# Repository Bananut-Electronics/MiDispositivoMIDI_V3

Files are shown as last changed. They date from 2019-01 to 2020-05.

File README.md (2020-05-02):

<h1 align="center"> ⭐️ MiDispositivoMIDI V3 ⭐️ </h1>

*This repository is no longer officially maintained but feel free to open a pull request with your contribution. As we ran out of devices, we don't sell it anymore, but if you you want one you can find here all the schematics, manuals, documentations and code to build your own.*
<!-- ALL-CONTRIBUTORS-BADGE:START - Do not remove or modify this section -->

<!-- ALL-CONTRIBUTORS-BADGE:END -->


<p align="center">
  <a href="www.facebook.com/bananutelectronics">
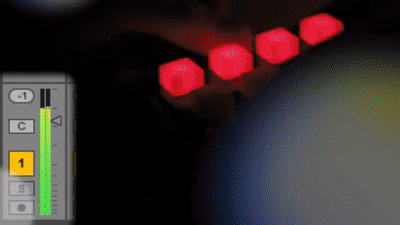
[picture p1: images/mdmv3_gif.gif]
    
  </a>
  
<p align="center">
  Connect our device to your computer and start making music! Totally Plug&Play without any extra software, just your favourite MIDI sequencer (Logic, Ableto, Nuendo). It is not only a great tool for making music and experimenting, you can also use it to learn more about electronics, programming and Arduino. You have tons of code examples ready to load, but if you feel up to it, you can also contribute with your code. And last but not least! It is open source! You can either buy it at our website, our build it yourself, all the schematics and code are available in this repository.
  <p align="center">
  <a href="www.facebook.com/bananutelectronics">
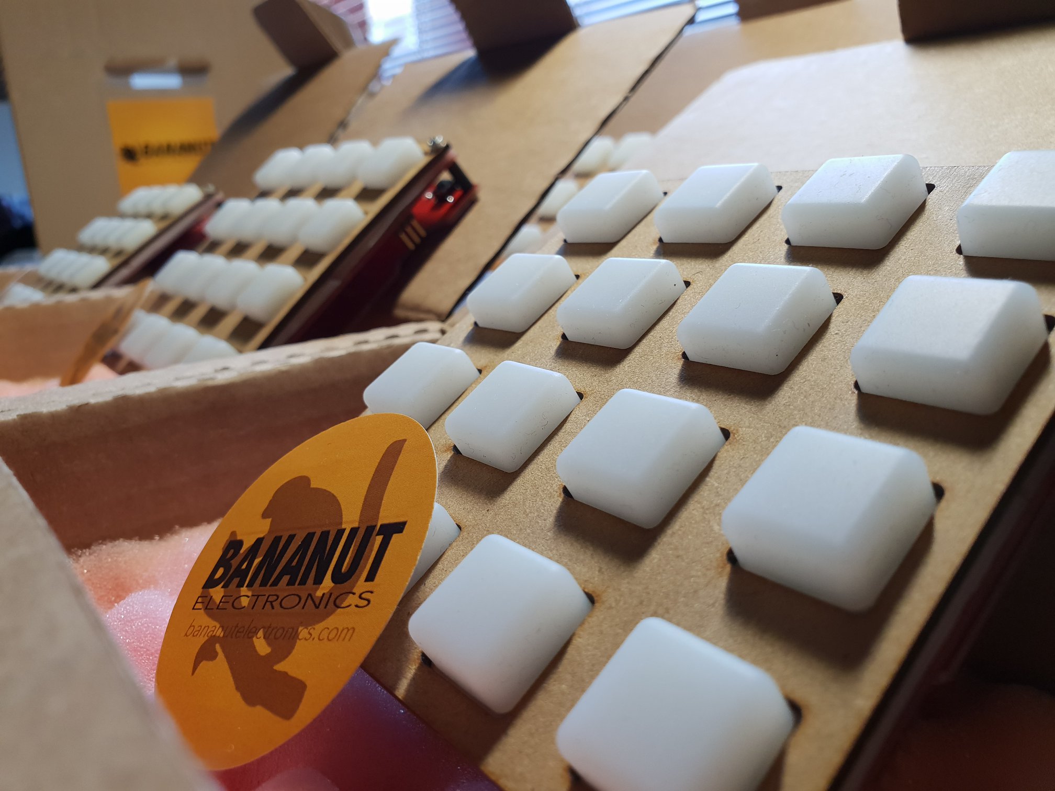
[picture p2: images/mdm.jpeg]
    
  </a>
</p>
</p>

---

<h2 align="center">❤️ Follow us! ❤️</h2>
<p align="center">
  <a href="https://www.facebook.com/bananutelectronics">
</a>
  
  <a href="https://www.instagram.com/bananutelectronics">
</a>

  <a href="https://github.com/Bananut-Electronics/">
</a>

  <a href="https://www.youtube.com/channel/UCHQbpOPa1lVauoBouRJ16Iw">
</a>

  <a href="https://twitter.com/bn_electronics">
</a>
</p>

---

<h2 align="center">💶 Want to buy the product? 💶</h2>

<p align="center">
  
</p>

---

<h2 align="center">📗 Index 📗</h2>

<p align="center">
  <a href="#about-us">About us</a> •
  <a href="#midispositivomidi-v3">MiDispositivoMIDI V3</a> •
  <a href="#documentation">Documentation</a> •
  <a href="#expansions">Expansions</a> •
  <a href="#faq">FAQ</a> •
  <a href="#contributing">Contributing</a> •
  <a href="#license">License</a>
</p>

---

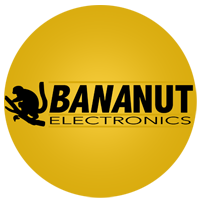
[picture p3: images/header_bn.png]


# About us
Hi! We are BanaNut Electronics and we develop software and hardware for Arduino with educational purposes. We were born at the UPM University in Madrid during 2013 and we haven't stopped ever since.

<center>

| LightWand Kosmonaut V2 |  MiDispositivoMIDI V3 |
|:---:|:---:|
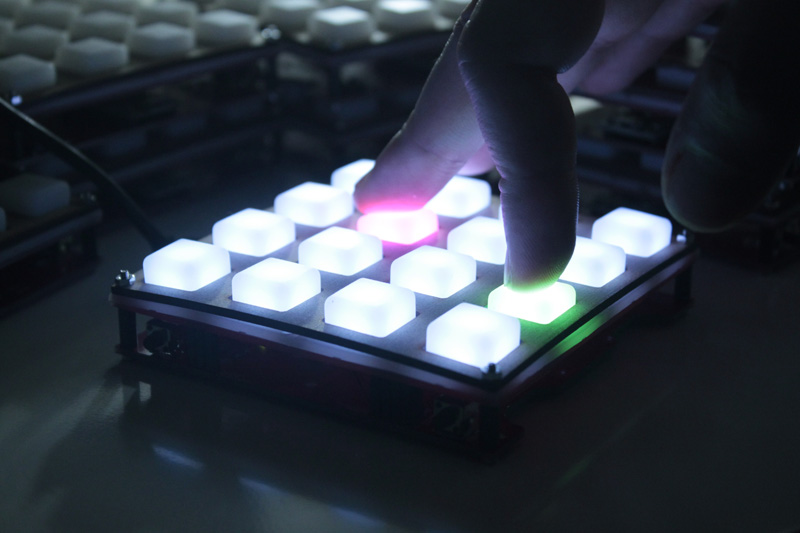
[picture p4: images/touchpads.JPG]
|   |  |

</center>

---

Everything started with the first version at the Polytechnical University of Madrid (UPM) in 2013. We were a couple of young students interested in music and electronics, and we came up with this idea. We started reusing some hardware, mainly found at SparkFun's website, but only one year later, we had the second version that was fully designed by us. After some trial and error and feedback from users and friends, we released this third version V3 in 2017. We not only released the code, but also we started producing devices and selling them on the internet, first in our web and later on at Tindie.com store.

During the years, the different versions of MiDispositivoMIDI have been used by many people, engineers, musicians and even kids. We gave some workshops at UPM Madrid for students in Electrical and Telecommunications Engineering, where we gave all the materials and the students had to solder, assembly and code the device.

<p align="center">
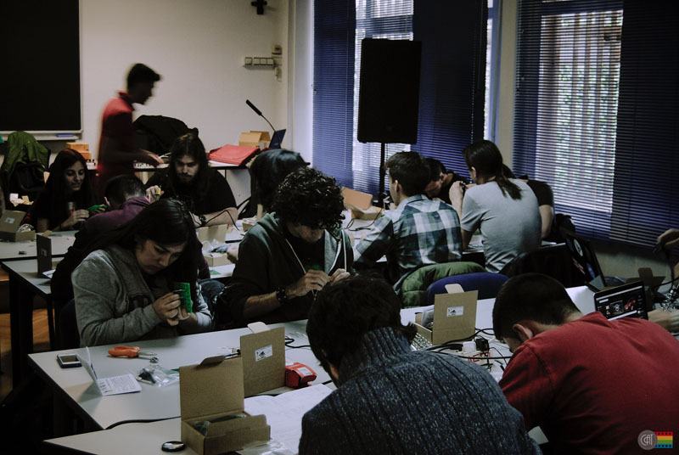
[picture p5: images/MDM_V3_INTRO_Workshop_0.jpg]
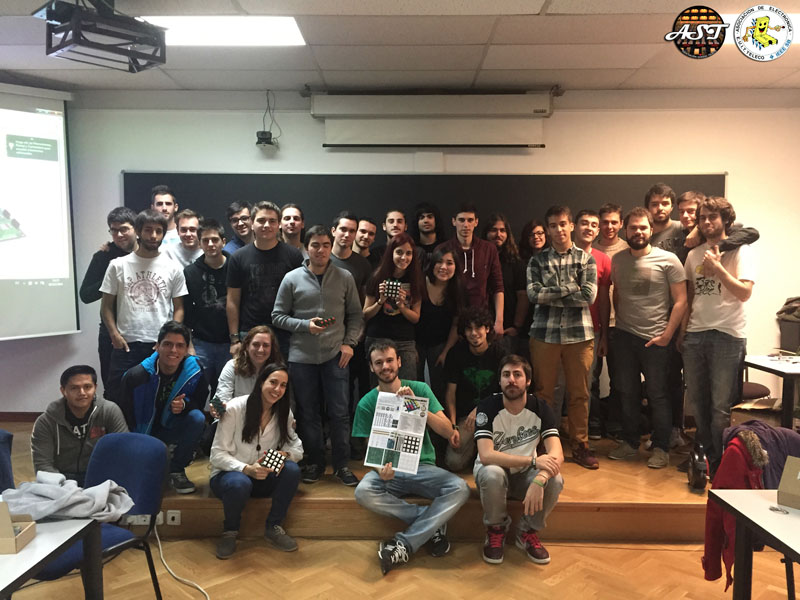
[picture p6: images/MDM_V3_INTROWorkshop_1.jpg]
  
</a>

---

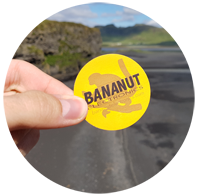
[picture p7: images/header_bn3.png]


# MiDispositivoMIDI V3
We are proud to present the MiDispositivoMIDI V3, which is the latest version we have out in the market (Jan 2019). MiDispositivoMIDI is an open source MIDI controller based on Arduino. In other words, its a small device with tons of LEDs and buttons, that you can connect to your computer to, in example, make music. Our device works with the MIDI protocol, a very well known protocol used in the music industry. You can just plug our device and start using it with your favourite DAW, such as Logic, Ableton or Cubase. No other extra softare is needed.

If you are also interested in programming and electronics, this device offer you a great tool to learn by example. You can also use it to prototype and play around. And also, since it is open source you can fully costumize it to your needs. If you don't know much about coding, just load the codes that we provide, and use them. But if you like coding, you can also publish your code with new features or improvements for others to use.

<p align="center">
<a href="www.facebook.com/bananutelectronics">
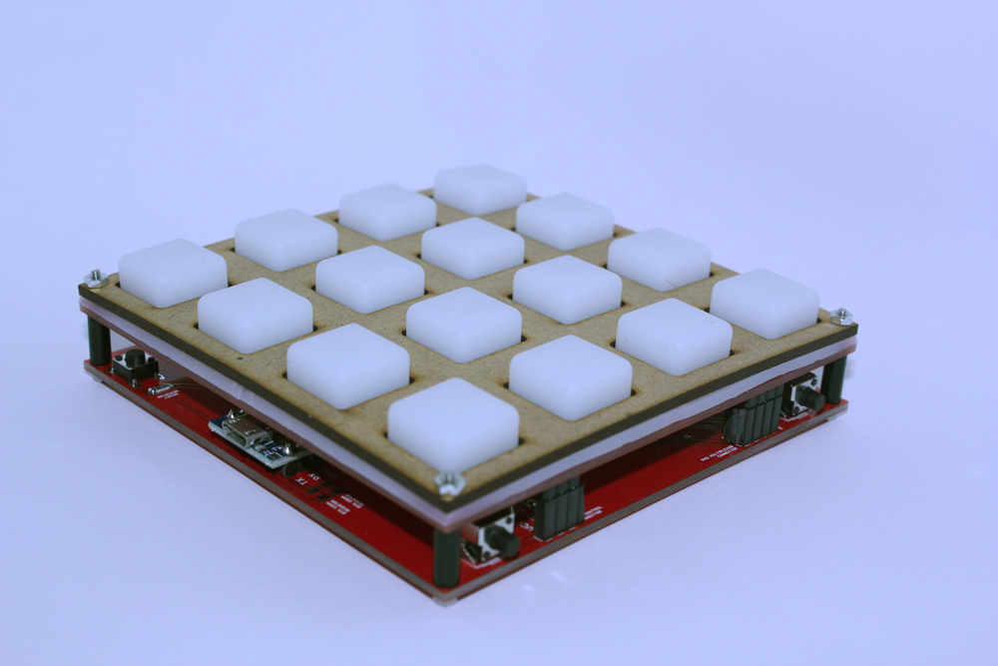
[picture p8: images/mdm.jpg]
    
</a>

<p align="center">
<a href="www.facebook.com/bananutelectronics">
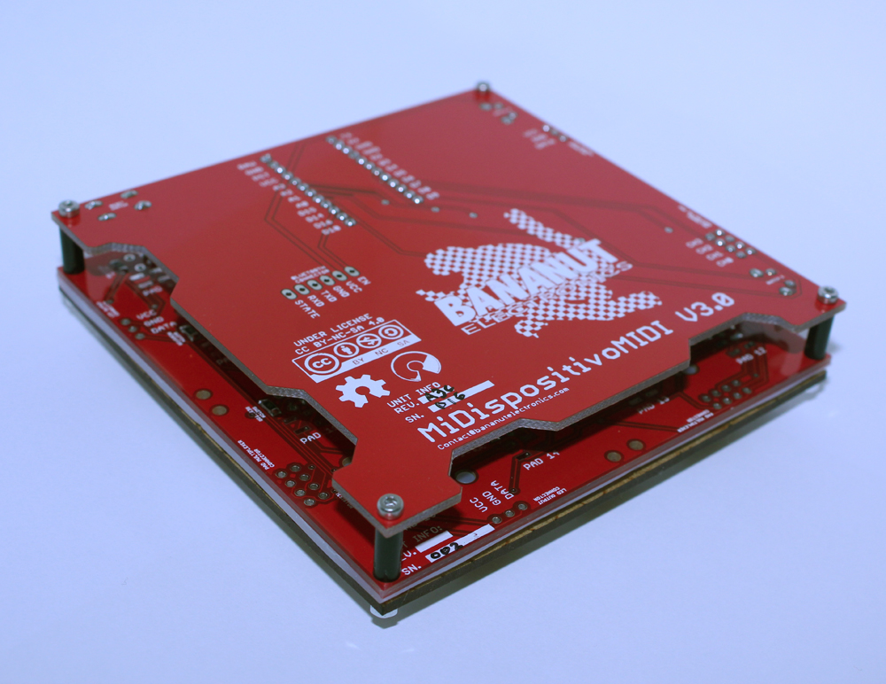
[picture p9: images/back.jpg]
    
</a>

These are the features of our device:
* Plug & Play MIDI device.
* Open source based on Arduino.
* Have 16 pad buttons in a 4x4 matrix.
* Have 2 lateral buttons.
* Have RGB leds with 256 levels of intensity of each color.
* Micro USB connection.
* Dimensions of 10x10 cm.
* Modular design. Connect up to 4 devices.
* Fully compatible with Logic, Ableton or Cubase.

<p align="center">
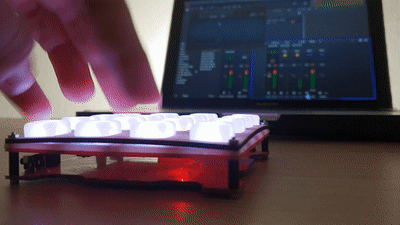
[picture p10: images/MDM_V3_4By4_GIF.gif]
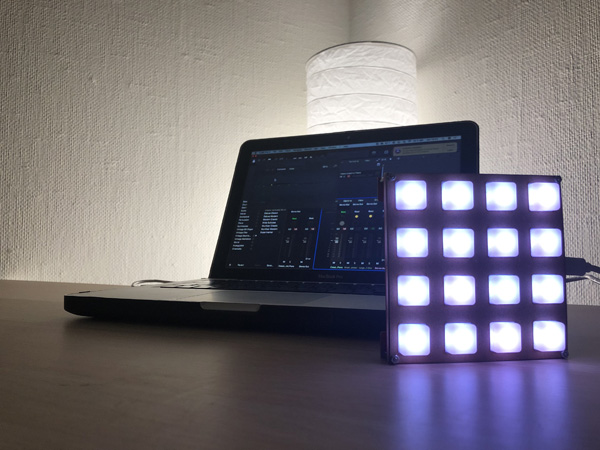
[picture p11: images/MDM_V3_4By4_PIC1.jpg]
  
</a>

We invite you to check our YouTube channel, where we post videos about our devices. You can also follow other social networks such as Instagram o Facebook.

* https://www.youtube.com/watch?v=3QnzLwpbpRE&t
* https://www.youtube.com/watch?v=8WFfShg-0Dk
* https://www.youtube.com/watch?v=2y8fhmTmedI
* https://www.youtube.com/watch?v=TsuVpFoLFyI

---

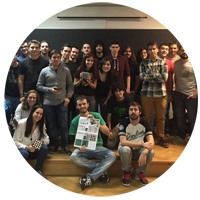
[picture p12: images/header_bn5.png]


# Documentation

We provide a C++ Arduino library that you can use with our device, that simplifies the tasks of handling the LEDs and buttons. The code is self documented, but we have also written a nice Wiki page where you can find more information about the hardware, some hints about MIDI protocol and some low level software examples in Arduino, that will allow you to understand how it works:
* Wiki: https://github.com/Bananut-Electronics/MiDispositivoMIDI_V3/wiki

TODO: Write some nice code snippets
```cpp
//TODO
```

---

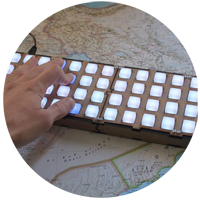
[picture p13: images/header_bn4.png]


# Expansions

Our device has a modular design, which means that with the same hardware, you can add modules to convert it into a bigger controller. For example, if you put four MiDispositivoMIDI V3 into a 8x8 configuration, you will have 64 buttons. All this can be done using the same hardware and with very few modificatons in the code. Note that you can also replace a 4x4 button matrix by a 4x4 potentiometer matrix, but this feature is not implemented yet.

<p align="center">
<a href="www.facebook.com/bananutelectronics">
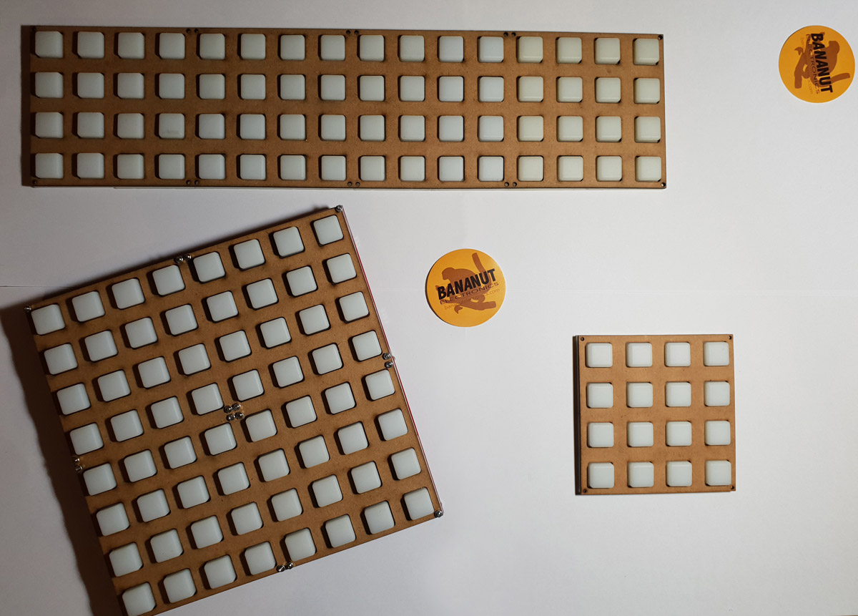
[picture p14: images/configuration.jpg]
    
</a>

## 4x16 Configuration

You can connect 4 MiDispositivoMIDI V3 in a 4x16 configuration to get the following. With something like this, you can, for example, create an step sequencer. See this video for an example:
* https://www.youtube.com/watch?v=bYyvVDn-gKs

<p align="center">
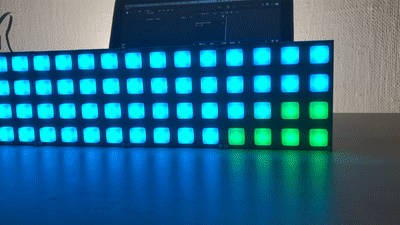
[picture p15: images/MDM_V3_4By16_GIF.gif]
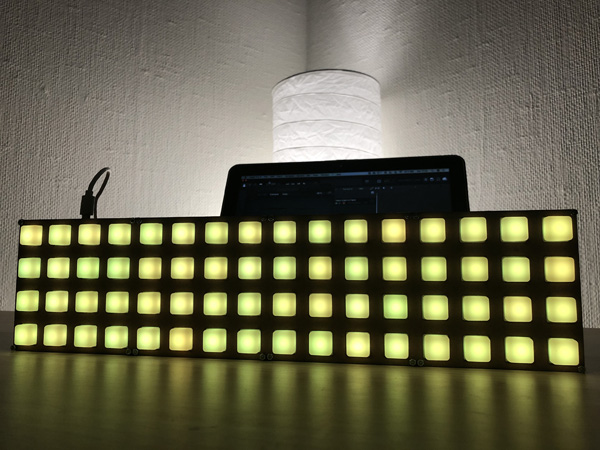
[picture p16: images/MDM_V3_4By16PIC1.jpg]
  
</a>

## 8x8 Configuration
Same as before, you can connect the devices with a different configuration. Note that the connections are done under the PCB with an extra PCB, so no extra wiring is needed.

<p align="center">
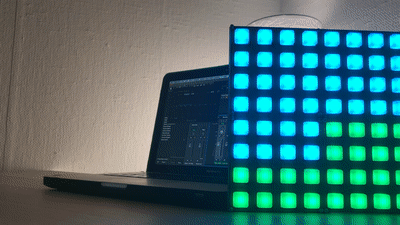
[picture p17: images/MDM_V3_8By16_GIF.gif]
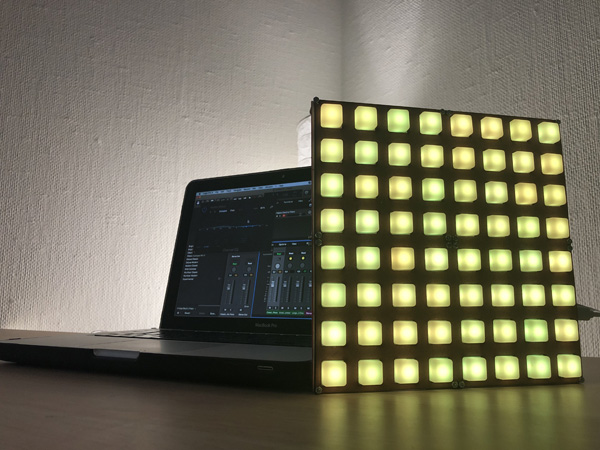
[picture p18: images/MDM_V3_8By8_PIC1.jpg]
  
</a>

## 4x8 Configuration
TODO

## Potentiometer Expansion
TODO

---

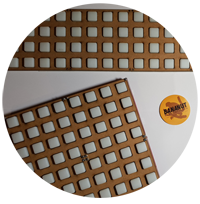
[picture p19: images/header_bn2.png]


# FAQ

Feel free to send us a mail to bananutelectronics@gmail.com if you have any question, but read before our FAQ since there are some common issues that can be fixed quite easily:

* **I can't load code to my device. Why?** Make sure that in the Arduino IDE boards section (Tool->Boards) you have selected "Arduino Leonardo"
* **I was playing with some code, and now the device is gone form the serial port list. Why?** If you were playing with some experimental code, you might have screwed up the "operative system" of the Arduino. But no worries, the fix is pretty straightforward. Open an example from the basic library (i.e. Examples->Basics-Blink) and hit the "Upload" button. You will first see that it is "Compiling" and that that is "Loading". Click the reset button right after "Compiling" is finished. With this you should get the bootloader running and you will be able to load the code. After this, you should be able to see the device in the serial port list as usual. Note that the reset button is the one on the top (not the ones on the left).
* **When I press a button, the LED takes a bit to light up, why?** There should not be any delay when you press a button, so right after pressing the pad, you should see that it lights up (assuming of course that it configured to do so). If this delay is present, please, make sure that you have a MIDI program reading the port in your computer.

---

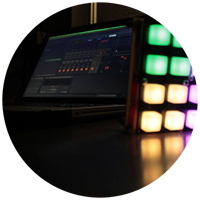
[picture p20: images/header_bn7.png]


# Contributing
Feel free to create a pull request with your new feature, we will be pleased to add it to our repo. We can differentiate between three different types of contributions:

* Contributing to the Arduino library: Feel free to add stuff related to our Arduino library in the `src` folder. Note that if you add a new feature to our library, we would love to see also a working example in the `examples` folder using that new functionality. Name if as `MDM_V3_Library_xxx` so that we know that that code uses the library.
* Contributing with new examples: You can add code inside the `examples` folder. Just remember to name it with `MDM_V3_NoLibrary_xxx` if that code is not using any function provided by the library.
* Other random stuff: Feel free to add images with your own setup, correct existing code, fix bugs or whatever you have in mind.

---

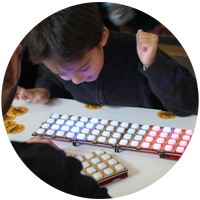
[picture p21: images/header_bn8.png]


# License

<br /><span xmlns:dct="http://purl.org/dc/terms/" property="dct:title">MiDispositivoMIDI</span> by <a xmlns:cc="http://creativecommons.org/ns#" href="www.bananutelectronics.com" property="cc:attributionName" rel="cc:attributionURL">Alvaro Lopez & Pablo de Miguel Morales</a> is licensed under a <a rel="license" href="http://creativecommons.org/licenses/by-nc-sa/4.0/">Creative Commons Attribution-NonCommercial-ShareAlike 4.0 International License</a>.<br />

## Contributors ✨

Thanks goes to these wonderful people ([emoji key](https://allcontributors.org/docs/en/emoji-key)):

<!-- ALL-CONTRIBUTORS-LIST:START - Do not remove or modify this section -->
<!-- prettier-ignore-start -->
<!-- markdownlint-disable -->
<table>
  <tr>
    <td align="center"><a href="https://github.com/pabloEntropia"><br /><sub><b>Pablo Alonso</b></sub></a><br /><a href="https://github.com/Bananut-Electronics/MiDispositivoMIDI_V3/commits?author=pabloEntropia" title="Code">💻</a></td>
    <td align="center"><a href="https://github.com/per1234"><br /><sub><b>per1234</b></sub></a><br /><a href="https://github.com/Bananut-Electronics/MiDispositivoMIDI_V3/commits?author=per1234" title="Code">💻</a></td>
  </tr>
</table>

<!-- markdownlint-enable -->
<!-- prettier-ignore-end -->
<!-- ALL-CONTRIBUTORS-LIST:END -->

This project follows the [all-contributors](https://github.com/all-contributors/all-contributors) specification. Contributions of any kind welcome!

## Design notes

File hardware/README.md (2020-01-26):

# Hardware

## Led Pad
Upper PCB, contains 16 leds LEDs and pad buttons

## Control Board
Lower PCB, contains the Arduino

## Pot Pad
Potentiometer expansion. **Important** This board is not officially supported yet and there might be a bug with some swapped pins. Do not send for production.

## Connector
Connects Pot Pads expansions.

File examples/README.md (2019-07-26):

# Examples

This section contains a list of examples for MiDispositivoMIDI that can be loaded to your device. Feel free to experiment! Some important notes about the examples
* Some examples use our Arduino library, others they don't.
* All examples are targeted to MiDispositivoMIDI V3, but note that there are several different configurations. Most of the codes will be ok for one MiDisopsitivoMIDI, but if you connect more than one, that code might not be valid.
* Have a new cool feature? Feel free to send us a pull request with some description of it, or maybe with a nice video!

# MDM_V3_NoLibrary_DefaultCode
TODO

# TODO

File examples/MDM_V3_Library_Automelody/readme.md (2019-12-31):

# Automelody Example
This example generates MIDI melodies based on a probabilistic model. When a `note button` is pressed, a new note with an automatically estimated pitch is produced.  The rest of the buttons on the board are intended to select between different melody models and to change the octave and root key.

## Melody models
The models were created by accumulating note bigrams from the MIDI transcriptions of different music pieces. The most repeated note is considered to be the root and the bigrams are normalized to C. 

There are 4 models:
- **RUMBITA.** From a popular Spanish rumba song.
- **BACH.** From Toccata and Fugue in D minor by J.S. Bach.
- **PACO.** From Paco de Lucia's Entre Dos Aguas.
- **CHINESE.** From a traditional Chinese composition.

On play-time, `note buttons` tell the system to generate a new note that is up to `N` semitones higher or lower than the previous one. `N` depends on which button was pressed. The system is not deterministic because it works by sampling from the probability distribution of all the notes on that range. 

The probability for each note is updated on each iteration depending on 3 factors: 
- **Note probability.** From the note counts from the bigrams.
- **Transition probability.** The probability of the note given the previous one.
- **The controlling factor.** This depends on which button was pressed. It penalizes notes that are far from `N`. Its goal is to make the system more controllable.

## Usage
### Note buttons
When `buttons 0 to 7` are pressed, a new note is generated. Buttons 0 to 3 generate a note that is lower than the previous one. The difference among them is the range of allowed notes that can be produced. 
- 0: [0, -2] semitones
- 1: [0, -4] semitones
- 2: [0, -7] semitones
- 3: [0, -10] semitones

This means that while `button 0` only allows the same, one or two semitones lower, `button 3` may produce almost all the notes in the scale. However, due to the controlling factor, values closer to -10 semitones will have a greater priority. 

`Buttons 4 to 7` have the same behavior for higher notes.

### Transposition buttons
By default, the model operates in C. Use the `buttons 10 to 11` to shift the root note by steps of one semitone up/down.

### Octave shift buttons
Use `buttons 8 to 9` to transpose the pitch one octave up/down. 

### Model buttons
4 different models can be exchanged in real-time. `Buttons 12 to 15` allow exchanging among models:
- 12 -> RUMBITA
- 13 -> BACH
- 14 -> PACO
- 15 -> CHINESE

## Future work
- Improve the models by using several tracks from the same style for each one. 
- Think on new ways of controlling the note generation process.

## Board layout
For the sake of clarity, the following table shows the position of the buttons on the board when the USB connection is pointting downwards.

| | | | | |
| -- | -- | -- | -- | -- |
| Model buttons | 15 | 14 | 13 | 12 |
| Oct. / trans. | 11 | 10 |  9 |  8 |
| Note buttons  | 7  |  6 |  5 |  4 |
| Note buttons  | 3  |  2 |  1 |  0 |

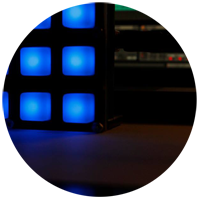
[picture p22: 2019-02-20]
images/header_bn6.png

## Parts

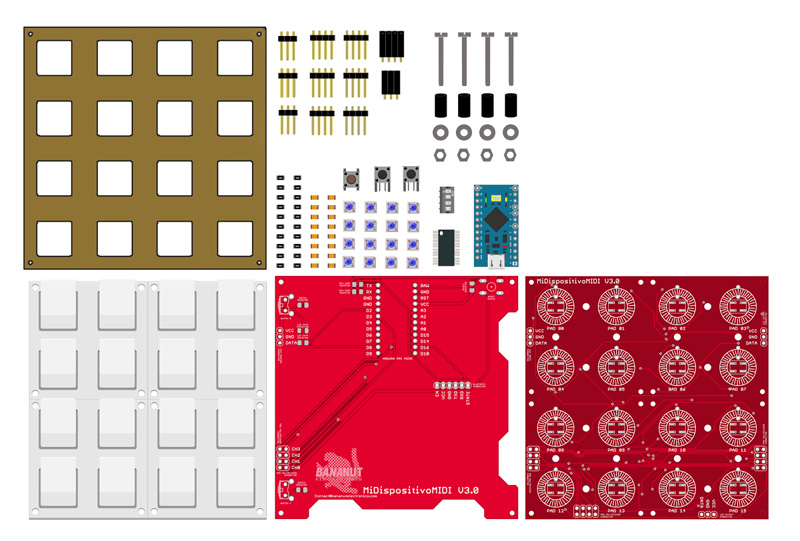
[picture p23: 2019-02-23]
images/MDM_V3_HW_Components.jpg

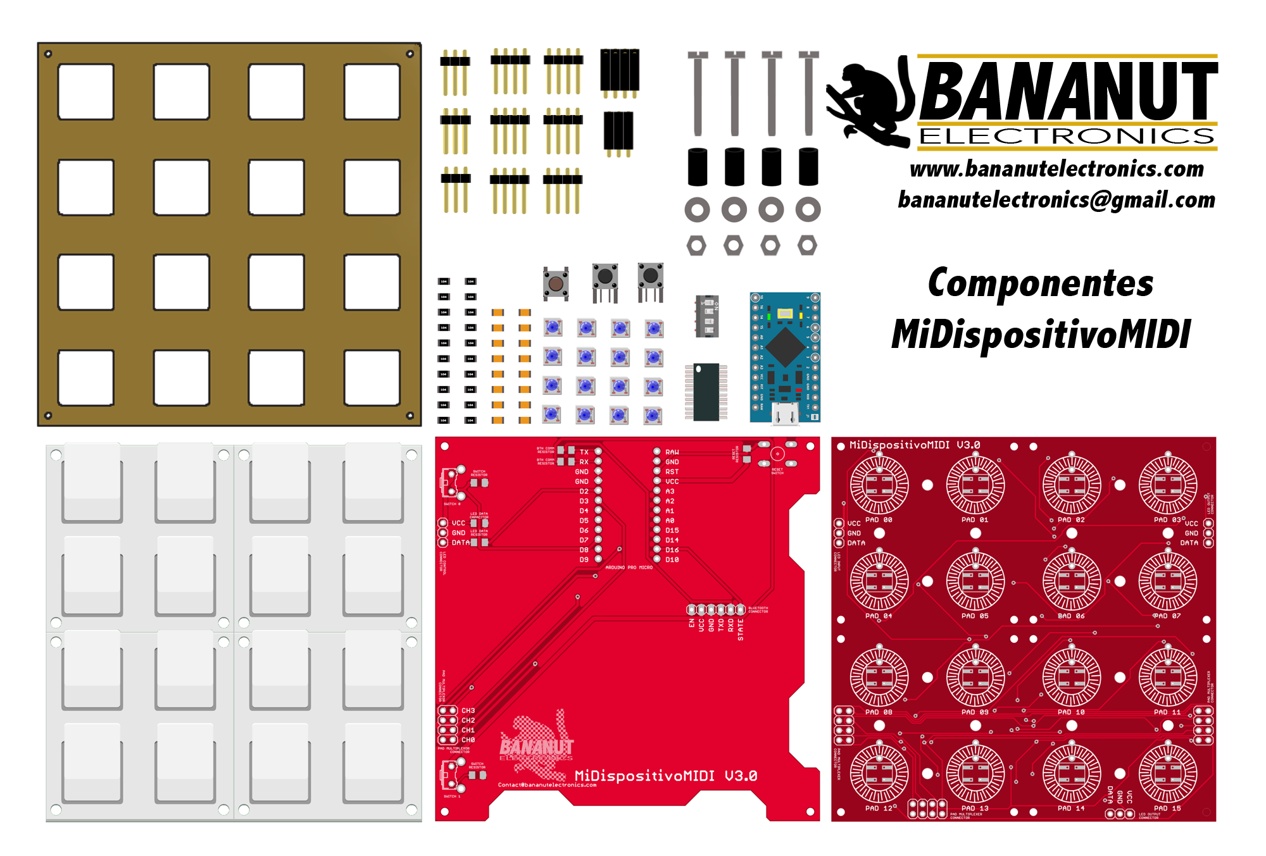
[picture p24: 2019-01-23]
images/components.png

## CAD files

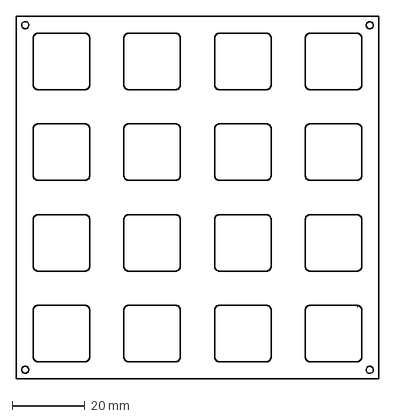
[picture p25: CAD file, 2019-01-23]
hardware/MDM_V3_Cover.dxf
100.0 x 100.0 mm

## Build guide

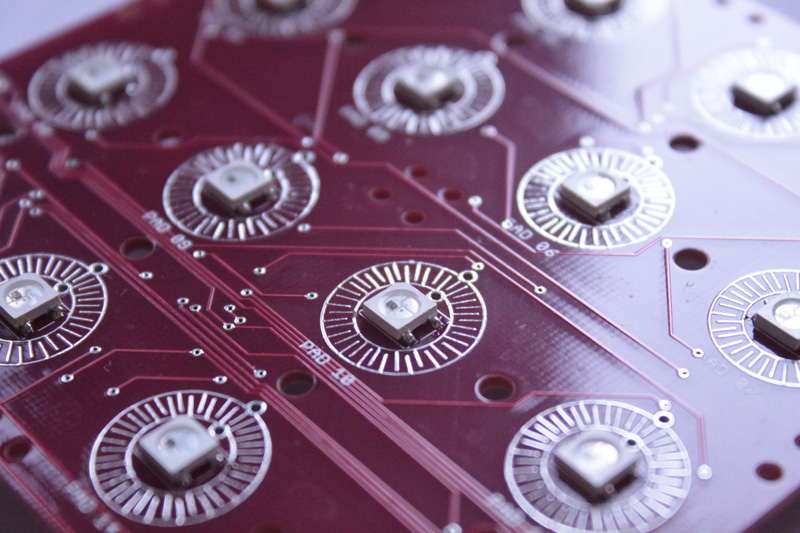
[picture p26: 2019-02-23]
images/MDM_V3_HW_LEDPad_LEDSoldered.JPG

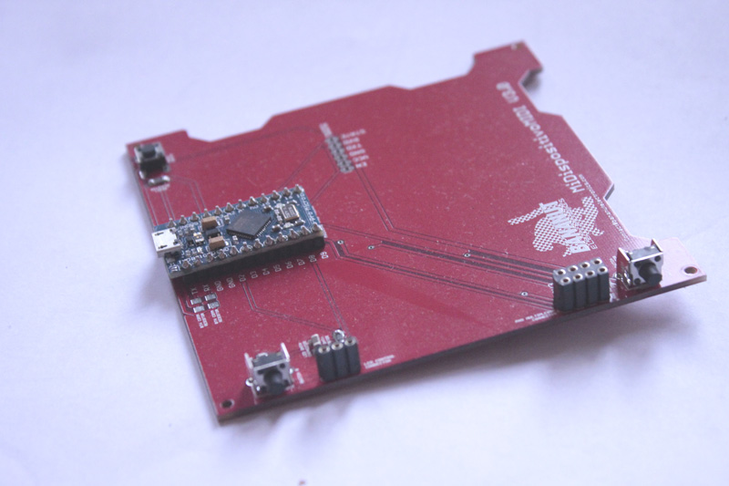
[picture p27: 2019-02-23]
images/MDM_V3_HW_CCOntrolBoard_FullSoldered.JPG

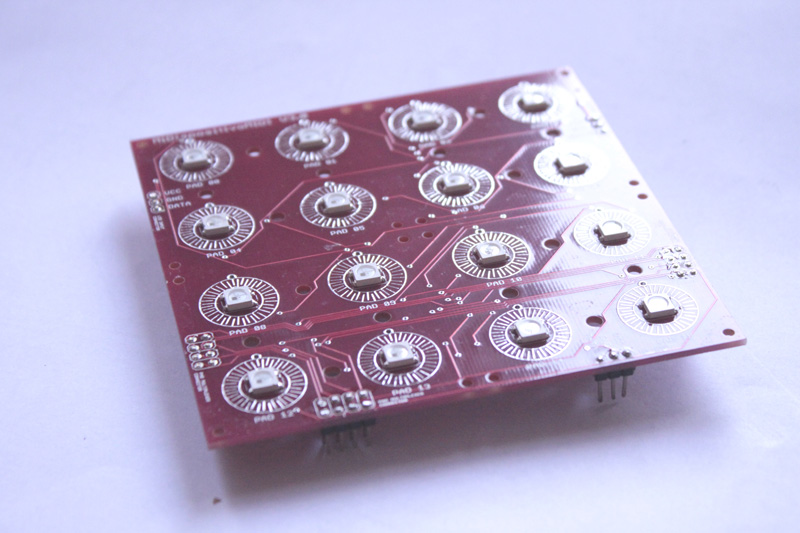
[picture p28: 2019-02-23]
images/MDM_V3_HW_LEDPad_FullSoldered.JPG

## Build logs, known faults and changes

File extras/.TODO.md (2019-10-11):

TODO:
Move here all the content that is not related to the library.

According to the doc:
An extras folder can be used by the developer to put documentation or other items to be bundled with the library. Remember that files placed inside this folder will increase the size of the library, so putting a 20MB PDF in a library that weights a few kilobytes may not be such a good idea.

The content of the extras folder is totally ignored by the IDE; you are free to put anything inside such as supporting documentation, etc.

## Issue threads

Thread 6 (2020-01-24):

Need help with led

4dvn, 2020-01-24:
I have to make the 4x4 buttons matrix on arduino pro micro but need help for ws2812 can change rgb ledtrip with velocity like midi fighter spectra

alrevuelta, 2020-01-24:
If I understood correctly, you would like to change the colour intensity of the RGB leds? If so, please have a look to [this example](https://github.com/Bananut-Electronics/MiDispositivoMIDI_V3/blob/master/examples/MDM_V3_Library_ConfigureColors/MDM_V3_Library_ConfigureColors.ino). The intensity is a value from 0 to 255, so if you set 100, it will be less brighter. First element in the array is R, second G and third B.

```c
void setup() {
  // Configure the colors when the LED is not pressed
  uint8_t offColors[3] = {255, 0, 0};
  mdm.setOffColors( offColors );

  // Configure the colors when the LED is pressed
  uint8_t onColors[3] = {0, 255, 0};
  mdm.setOnColors( onColors );
}
```

4dvn, 2020-01-24:
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

Is that possible to adding more color than 3 color basic?

alrevuelta, 2020-01-24:
Regarding your first question "Is that possible to adding more color than 3 color basic?" Yes, it is possible, you can do something like `{100, 25, 200}` and you will be mixing some red with a bit of green and a lot of blue.

If you load the code that I mentioned above, you should be able to see the colours that you have configured. I assume that you have a MIDI receiver open in the computer. Let me know if it doesn't work for you, but please, state your problem with providing more details.

4dvn, 2020-01-25:
I thing the library need to separate like MIDIUSB library to add zip library on arduino ide, i need the schematic before made the pcb, can you define the pinout to me, thank you!

alrevuelta, 2020-01-25:
All the documentation can be found in this repo. For pinout refer either to the [Wiki](https://github.com/Bananut-Electronics/MiDispositivoMIDI_V3/wiki) or the pcb schematics [here](https://github.com/Bananut-Electronics/MiDispositivoMIDI_V3/tree/master/hardware)

Since your initial question was already answered, I'm closing this.

Closed 2020-01-25.

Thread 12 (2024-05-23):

I need help

DRCRecoveryData, 2024-05-23:
Hi,

How config leds to show animation like this when press buttons:

https://youtu.be/3QnzLwpbpRE?si=uAweJyFWsB0KYP-8

dawidnaessie, 2024-05-26:
bait link dont click

DRCRecoveryData, 2024-05-27:
> bait link dont click

main channel youtube link of owner are you serious?

alrevuelta, 2024-05-27:
[This example](https://github.com/Bananut-Electronics/MiDispositivoMIDI_V3/blob/master/examples/MDM_V3_Library4x16/MDM_V3_Library4x16.ino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) might be useful for the animations you are asking for. See `doFunnyAnimation`. By using `mdm.setInterrupt(doFunnyAnimation, 0.025);` you are doing the provided animation every `.025 sec`.

Note that this example is meant for devices with 4x16 buttons. If yours has 4x4, you would need just to change a couple of lines, see below. You can use [this example](https://github.com/Bananut-Electronics/MiDispositivoMIDI_V3/blob/master/examples/MDM_V3_Library_ConfigureColors/MDM_V3_Library_ConfigureColors.ino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) as reference mixed with the other one.

```
BoardRoles bRoles[1] = {TOUCHPAD};
MiDispositivoMIDI_V3 mdm = MiDispositivoMIDI_V3(SINGLE_DEVICE_4X4, bRoles);
```

DRCRecoveryData, 2024-05-28:
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

I have made script for 8x8 in here:

https://github.com/DRCRecoveryData/mf64-promicro/blob/main/8x8_leds.ino

DRCRecoveryData, 2024-09-04:
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

Can i use sanwa arcade by your touchpad cose?

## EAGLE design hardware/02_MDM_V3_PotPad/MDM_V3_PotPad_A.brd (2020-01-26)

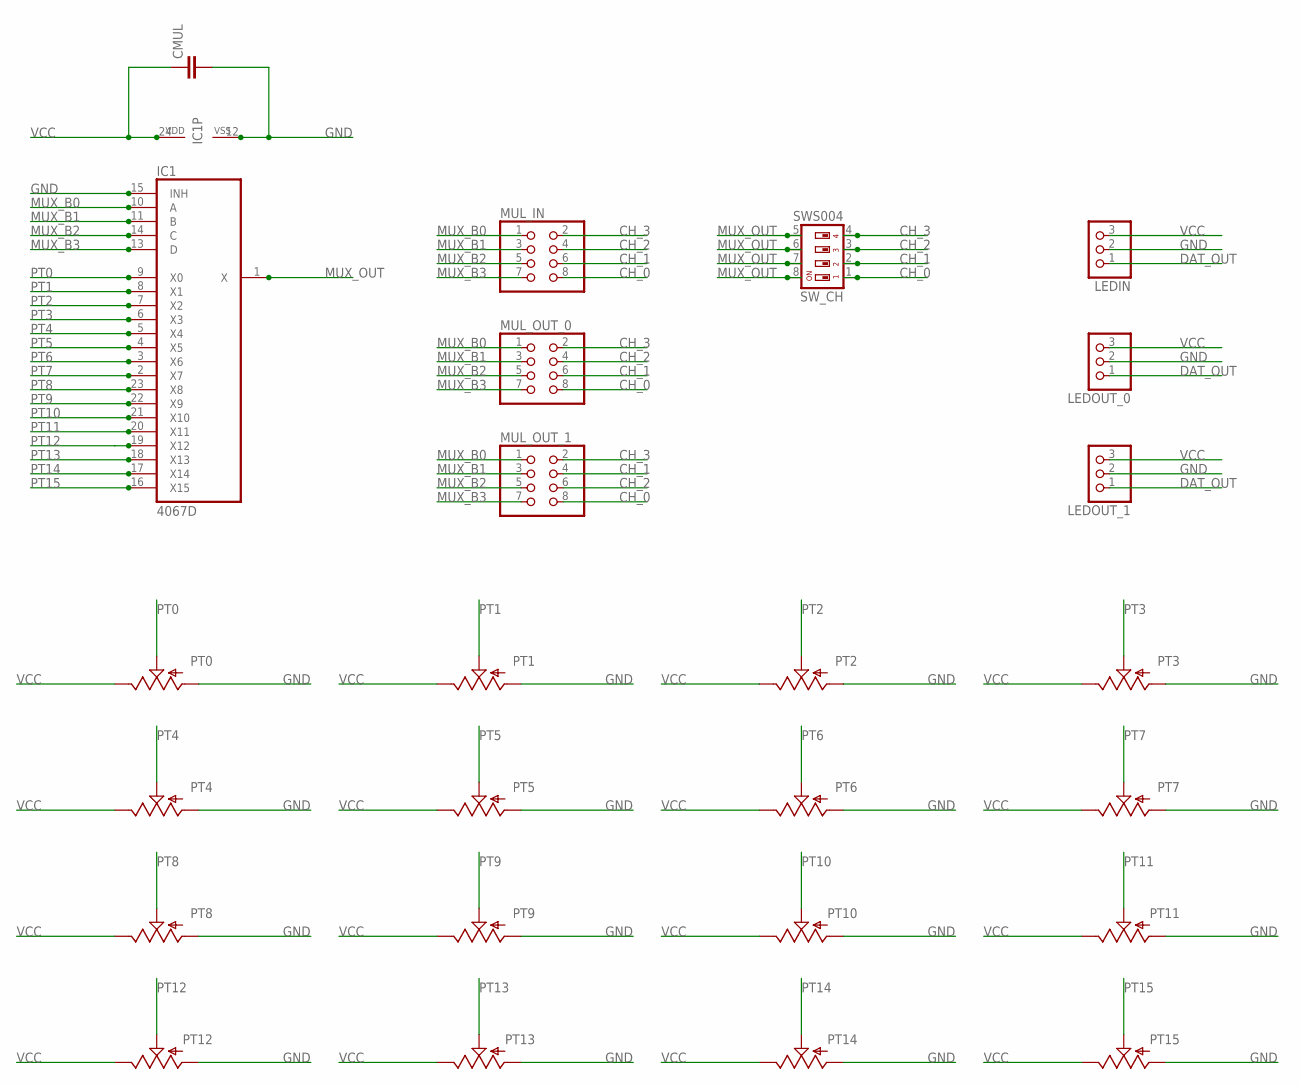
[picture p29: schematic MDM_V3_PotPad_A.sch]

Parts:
CMUL: C-EUC1206K; C1206K
IC1: 4067D; SO24W
LEDIN: PINHD-1X3; 1X03
LEDOUT_0, LEDOUT_1: PINHD-1X3; 1X03
MUL_IN: PINHD-2X4; 2X04
MUL_OUT_0, MUL_OUT_1: PINHD-2X4; 2X04
PT0, PT1, PT2, PT3, PT4, PT5, PT6, PT7, PT8, PT9, PT10, PT11, PT12, PT13, PT14, PT15: POT; ALPS_POT
SW_CH: SWS004; SMS-004

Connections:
CH_0: MUL_IN.8, MUL_OUT_0.8, MUL_OUT_1.8, SW_CH.1
CH_1: MUL_IN.6, MUL_OUT_0.6, MUL_OUT_1.4, SW_CH.2
CH_2: MUL_IN.4, MUL_OUT_0.4, MUL_OUT_1.6, SW_CH.3
CH_3: MUL_IN.2, MUL_OUT_0.2, MUL_OUT_1.2, SW_CH.4
DAT_OUT: LEDIN.1, LEDOUT_0.1, LEDOUT_1.1
GND: CMUL.2, IC1.12 (VSS), IC1.15 (INH), LEDIN.2, LEDOUT_0.2, LEDOUT_1.2, PT0.P$3 (A), PT1.P$3 (A), PT2.P$3 (A), PT3.P$3 (A), PT4.P$3 (A), PT5.P$3 (A), PT6.P$3 (A), PT7.P$3 (A), PT8.P$3 (A), PT9.P$3 (A), PT10.P$3 (A), PT11.P$3 (A), PT12.P$3 (A), PT13.P$3 (A), PT14.P$3 (A), PT15.P$3 (A)
MUX_B0: IC1.10 (A), MUL_IN.1, MUL_OUT_0.1, MUL_OUT_1.1
MUX_B1: IC1.11 (B), MUL_IN.3, MUL_OUT_0.3, MUL_OUT_1.3
MUX_B2: IC1.14 (C), MUL_IN.5, MUL_OUT_0.5, MUL_OUT_1.5
MUX_B3: IC1.13 (D), MUL_IN.7, MUL_OUT_0.7, MUL_OUT_1.7
MUX_OUT: IC1.1 (X), SW_CH.5, SW_CH.6, SW_CH.7, SW_CH.8
PT0: IC1.9 (X0), PT0.P$2 (S)
PT1: IC1.8 (X1), PT1.P$2 (S)
PT2: IC1.7 (X2), PT2.P$2 (S)
PT3: IC1.6 (X3), PT3.P$2 (S)
PT4: IC1.5 (X4), PT4.P$2 (S)
PT5: IC1.4 (X5), PT5.P$2 (S)
PT6: IC1.3 (X6), PT6.P$2 (S)
PT7: IC1.2 (X7), PT7.P$2 (S)
PT8: IC1.23 (X8), PT8.P$2 (S)
PT9: IC1.22 (X9), PT9.P$2 (S)
PT10: IC1.21 (X10), PT10.P$2 (S)
PT11: IC1.20 (X11), PT11.P$2 (S)
PT12: IC1.19 (X12), PT12.P$2 (S)
PT13: IC1.18 (X13), PT13.P$2 (S)
PT14: IC1.17 (X14), PT14.P$2 (S)
PT15: IC1.16 (X15), PT15.P$2 (S)
VCC: CMUL.1, IC1.24 (VDD), LEDIN.3, LEDOUT_0.3, LEDOUT_1.3, PT0.P$1 (E), PT1.P$1 (E), PT2.P$1 (E), PT3.P$1 (E), PT4.P$1 (E), PT5.P$1 (E), PT6.P$1 (E), PT7.P$1 (E), PT8.P$1 (E), PT9.P$1 (E), PT10.P$1 (E), PT11.P$1 (E), PT12.P$1 (E), PT13.P$1 (E), PT14.P$1 (E), PT15.P$1 (E)

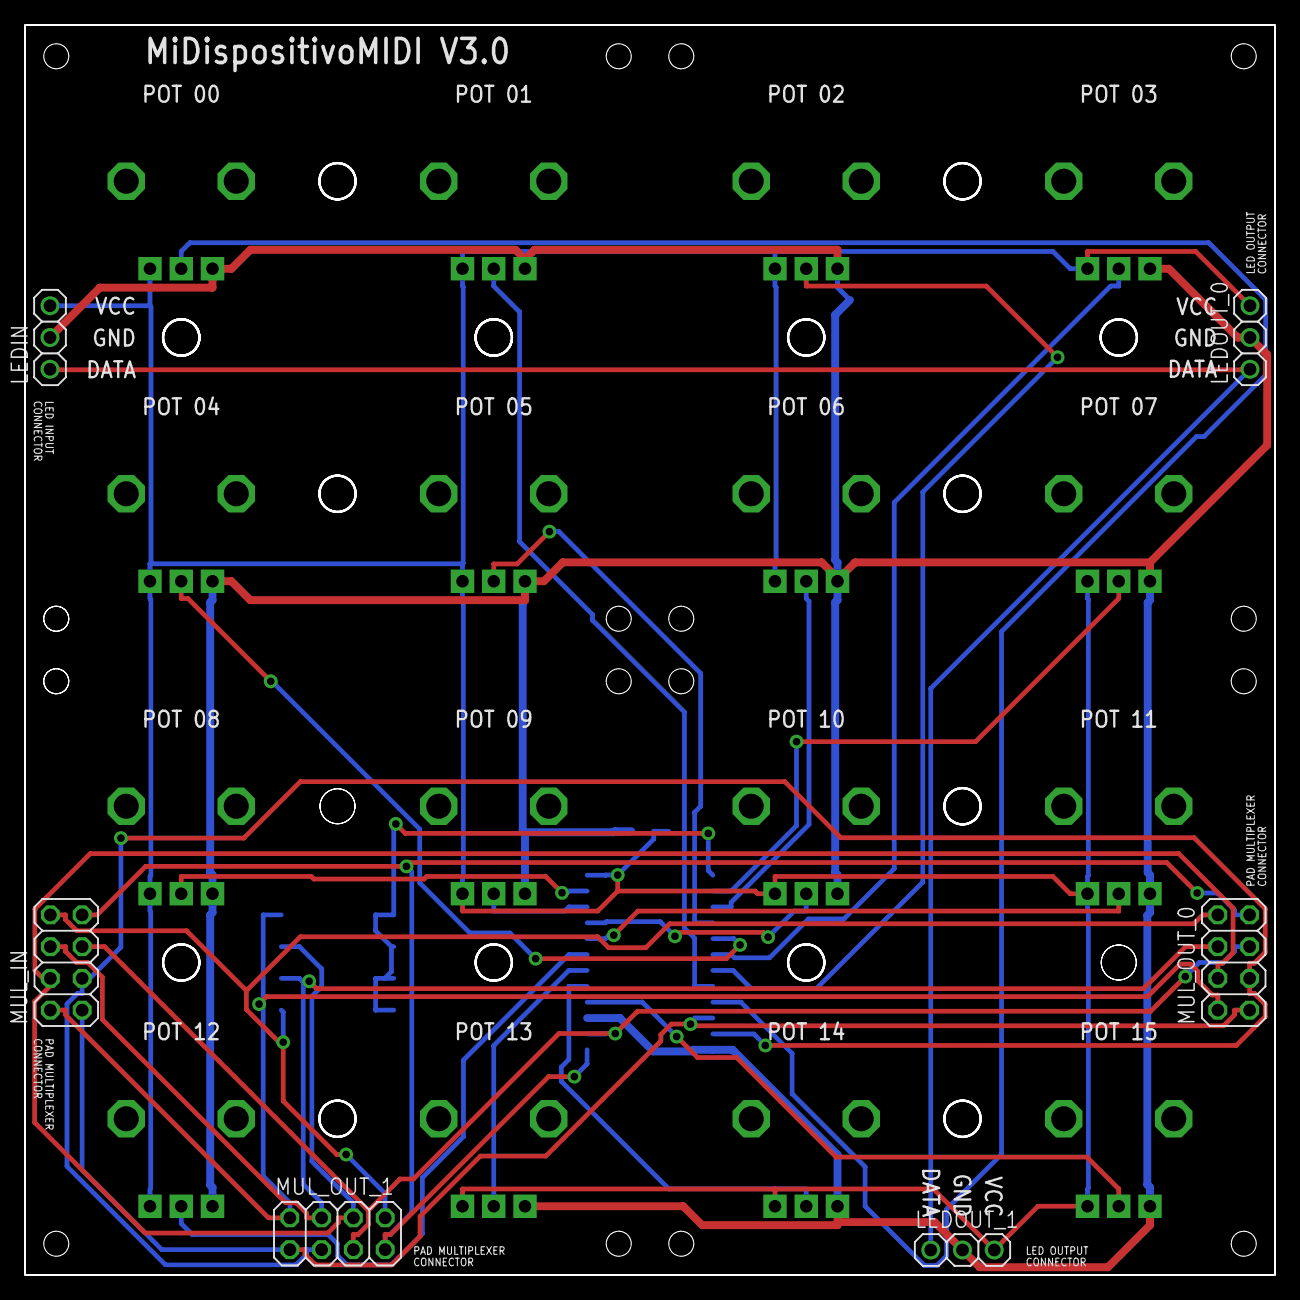
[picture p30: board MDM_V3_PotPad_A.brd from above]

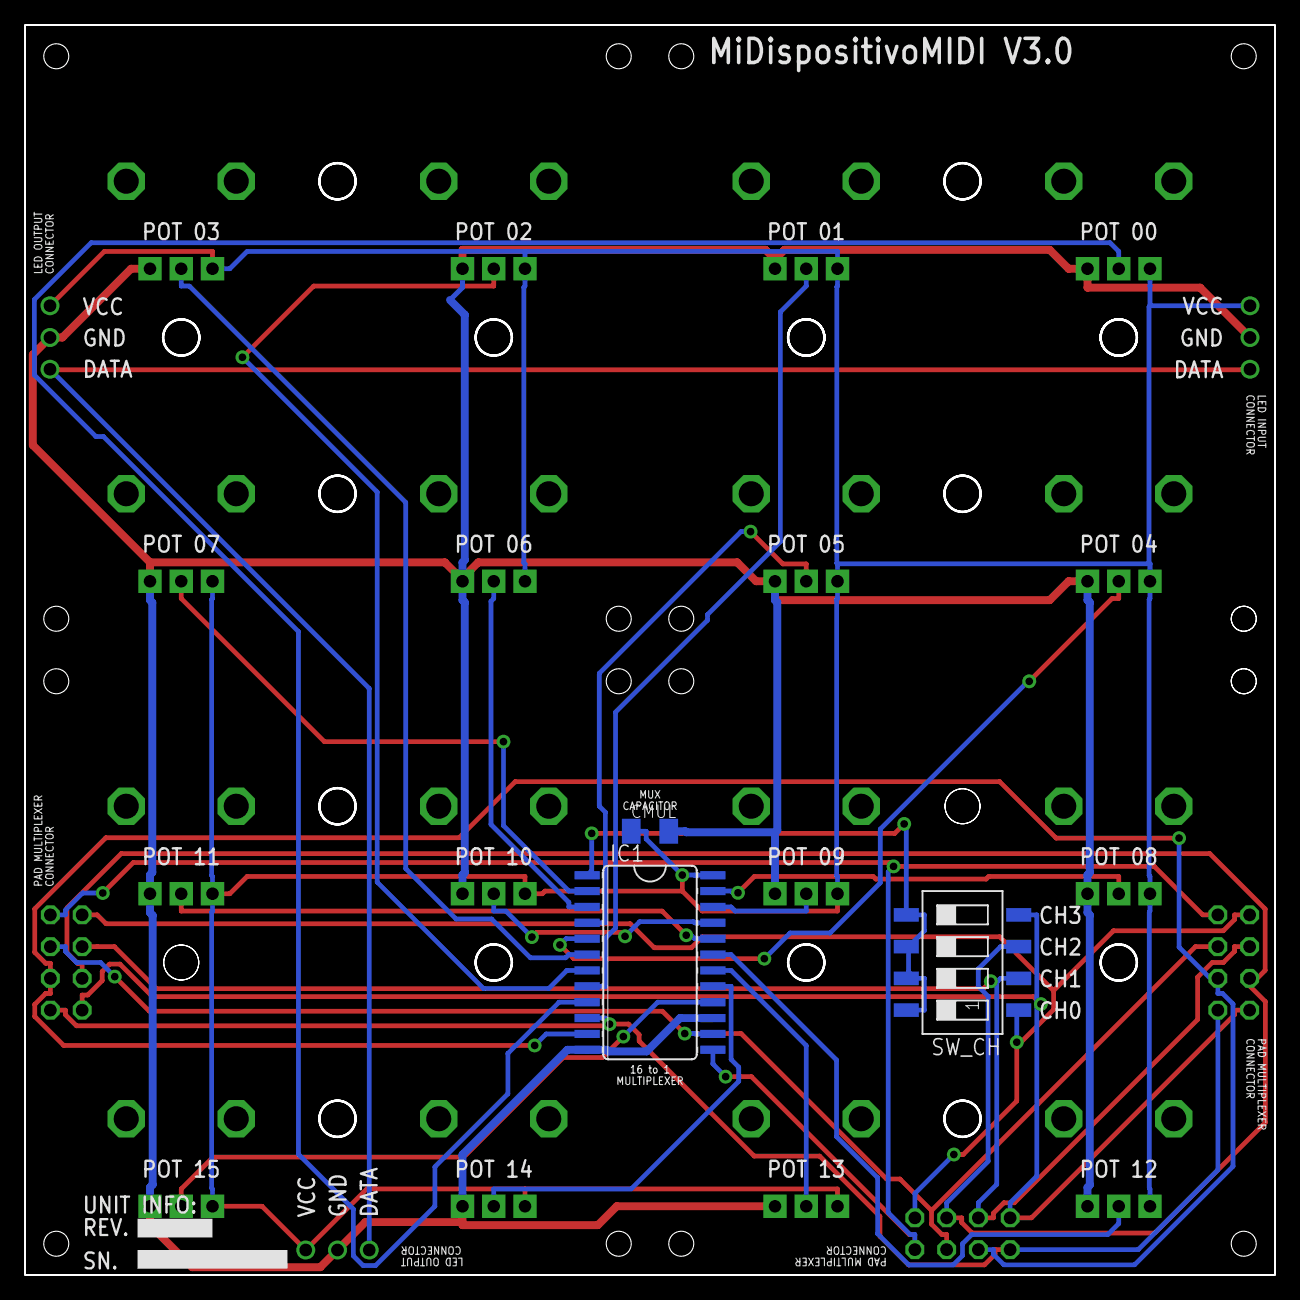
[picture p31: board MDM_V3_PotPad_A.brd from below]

Board: 2 copper layers, 100.0 x 100.0 mm, 25 parts (3 on the bottom side), 28 nets.

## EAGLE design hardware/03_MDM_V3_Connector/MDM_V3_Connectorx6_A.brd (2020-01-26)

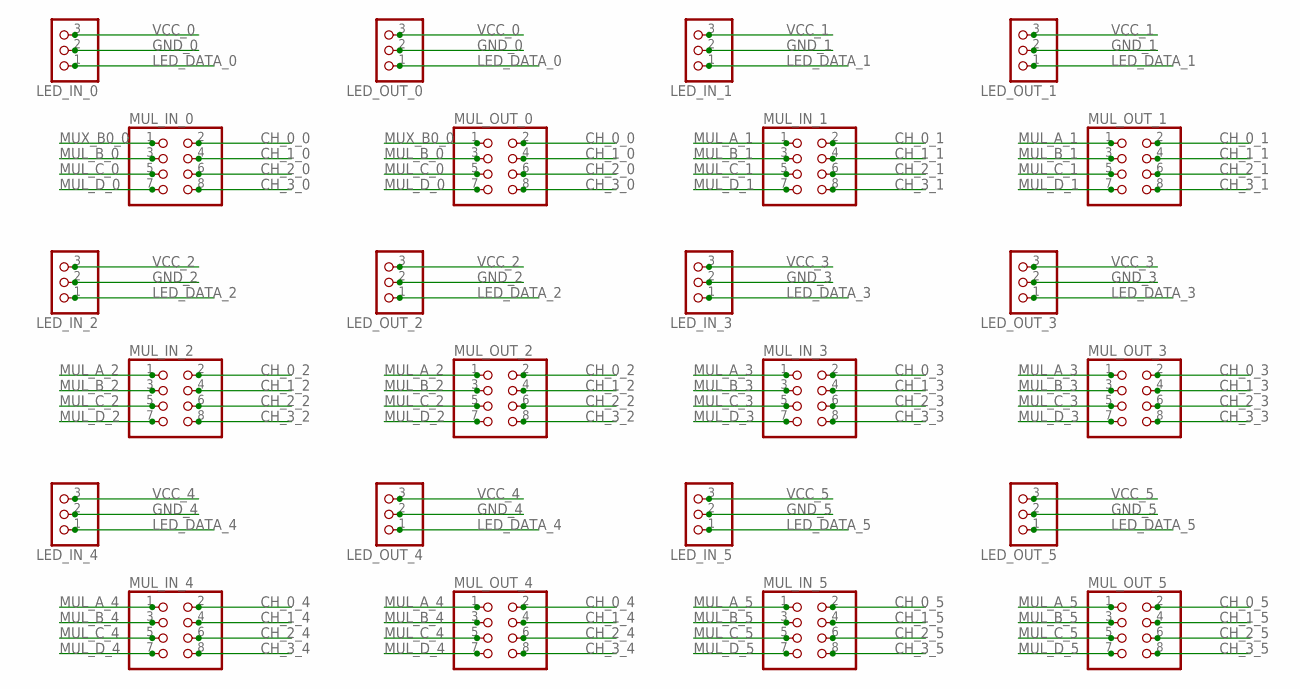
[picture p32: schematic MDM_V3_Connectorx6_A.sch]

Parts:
LED_IN_0, LED_IN_1, LED_IN_2, LED_IN_3, LED_IN_4, LED_IN_5: PINHD-1X3; 1X03
LED_OUT_0, LED_OUT_1, LED_OUT_2, LED_OUT_3, LED_OUT_4, LED_OUT_5: PINHD-1X3; 1X03
MUL_IN_0, MUL_IN_1, MUL_IN_2, MUL_IN_3, MUL_IN_4, MUL_IN_5: PINHD-2X4; 2X04
MUL_OUT_0, MUL_OUT_1, MUL_OUT_2, MUL_OUT_3, MUL_OUT_4, MUL_OUT_5: PINHD-2X4; 2X04

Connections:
CH_0_0: MUL_IN_0.2, MUL_OUT_0.2
CH_0_1: MUL_IN_1.2, MUL_OUT_1.2
CH_0_2: MUL_IN_2.2, MUL_OUT_2.2
CH_0_3: MUL_IN_3.2, MUL_OUT_3.2
CH_0_4: MUL_IN_4.2, MUL_OUT_4.2
CH_0_5: MUL_IN_5.2, MUL_OUT_5.2
CH_1_0: MUL_IN_0.4, MUL_OUT_0.4
CH_1_1: MUL_IN_1.4, MUL_OUT_1.4
CH_1_2: MUL_IN_2.4, MUL_OUT_2.4
CH_1_3: MUL_IN_3.4, MUL_OUT_3.4
CH_1_4: MUL_IN_4.4, MUL_OUT_4.4
CH_1_5: MUL_IN_5.4, MUL_OUT_5.4
CH_2_0: MUL_IN_0.6, MUL_OUT_0.6
CH_2_1: MUL_IN_1.6, MUL_OUT_1.6
CH_2_2: MUL_IN_2.6, MUL_OUT_2.6
CH_2_3: MUL_IN_3.6, MUL_OUT_3.6
CH_2_4: MUL_IN_4.6, MUL_OUT_4.6
CH_2_5: MUL_IN_5.6, MUL_OUT_5.6
CH_3_0: MUL_IN_0.8, MUL_OUT_0.8
CH_3_1: MUL_IN_1.8, MUL_OUT_1.8
CH_3_2: MUL_IN_2.8, MUL_OUT_2.8
CH_3_3: MUL_IN_3.8, MUL_OUT_3.8
CH_3_4: MUL_IN_4.8, MUL_OUT_4.8
CH_3_5: MUL_IN_5.8, MUL_OUT_5.8
GND_0: LED_IN_0.2, LED_OUT_0.2
GND_1: LED_IN_1.2, LED_OUT_1.2
GND_2: LED_IN_2.2, LED_OUT_2.2
GND_3: LED_IN_3.2, LED_OUT_3.2
GND_4: LED_IN_4.2, LED_OUT_4.2
GND_5: LED_IN_5.2, LED_OUT_5.2
LED_DATA_0: LED_IN_0.1, LED_OUT_0.1
LED_DATA_1: LED_IN_1.1, LED_OUT_1.1
LED_DATA_2: LED_IN_2.1, LED_OUT_2.1
LED_DATA_3: LED_IN_3.1, LED_OUT_3.1
LED_DATA_4: LED_IN_4.1, LED_OUT_4.1
LED_DATA_5: LED_IN_5.1, LED_OUT_5.1
MUL_A_1: MUL_IN_1.1, MUL_OUT_1.1
MUL_A_2: MUL_IN_2.1, MUL_OUT_2.1
MUL_A_3: MUL_IN_3.1, MUL_OUT_3.1
MUL_A_4: MUL_IN_4.1, MUL_OUT_4.1
MUL_A_5: MUL_IN_5.1, MUL_OUT_5.1
MUL_B_0: MUL_IN_0.3, MUL_OUT_0.3
MUL_B_1: MUL_IN_1.3, MUL_OUT_1.3
MUL_B_2: MUL_IN_2.3, MUL_OUT_2.3
MUL_B_3: MUL_IN_3.3, MUL_OUT_3.3
MUL_B_4: MUL_IN_4.3, MUL_OUT_4.3
MUL_B_5: MUL_IN_5.3, MUL_OUT_5.3
MUL_C_0: MUL_IN_0.5, MUL_OUT_0.5
MUL_C_1: MUL_IN_1.5, MUL_OUT_1.5
MUL_C_2: MUL_IN_2.5, MUL_OUT_2.5
MUL_C_3: MUL_IN_3.5, MUL_OUT_3.5
MUL_C_4: MUL_IN_4.5, MUL_OUT_4.5
MUL_C_5: MUL_IN_5.5, MUL_OUT_5.5
MUL_D_0: MUL_IN_0.7, MUL_OUT_0.7
MUL_D_1: MUL_IN_1.7, MUL_OUT_1.7
MUL_D_2: MUL_IN_2.7, MUL_OUT_2.7
MUL_D_3: MUL_IN_3.7, MUL_OUT_3.7
MUL_D_4: MUL_IN_4.7, MUL_OUT_4.7
MUL_D_5: MUL_IN_5.7, MUL_OUT_5.7
MUX_B0_0: MUL_IN_0.1, MUL_OUT_0.1
VCC_0: LED_IN_0.3, LED_OUT_0.3
VCC_1: LED_IN_1.3, LED_OUT_1.3
VCC_2: LED_IN_2.3, LED_OUT_2.3
VCC_3: LED_IN_3.3, LED_OUT_3.3
VCC_4: LED_IN_4.3, LED_OUT_4.3
VCC_5: LED_IN_5.3, LED_OUT_5.3

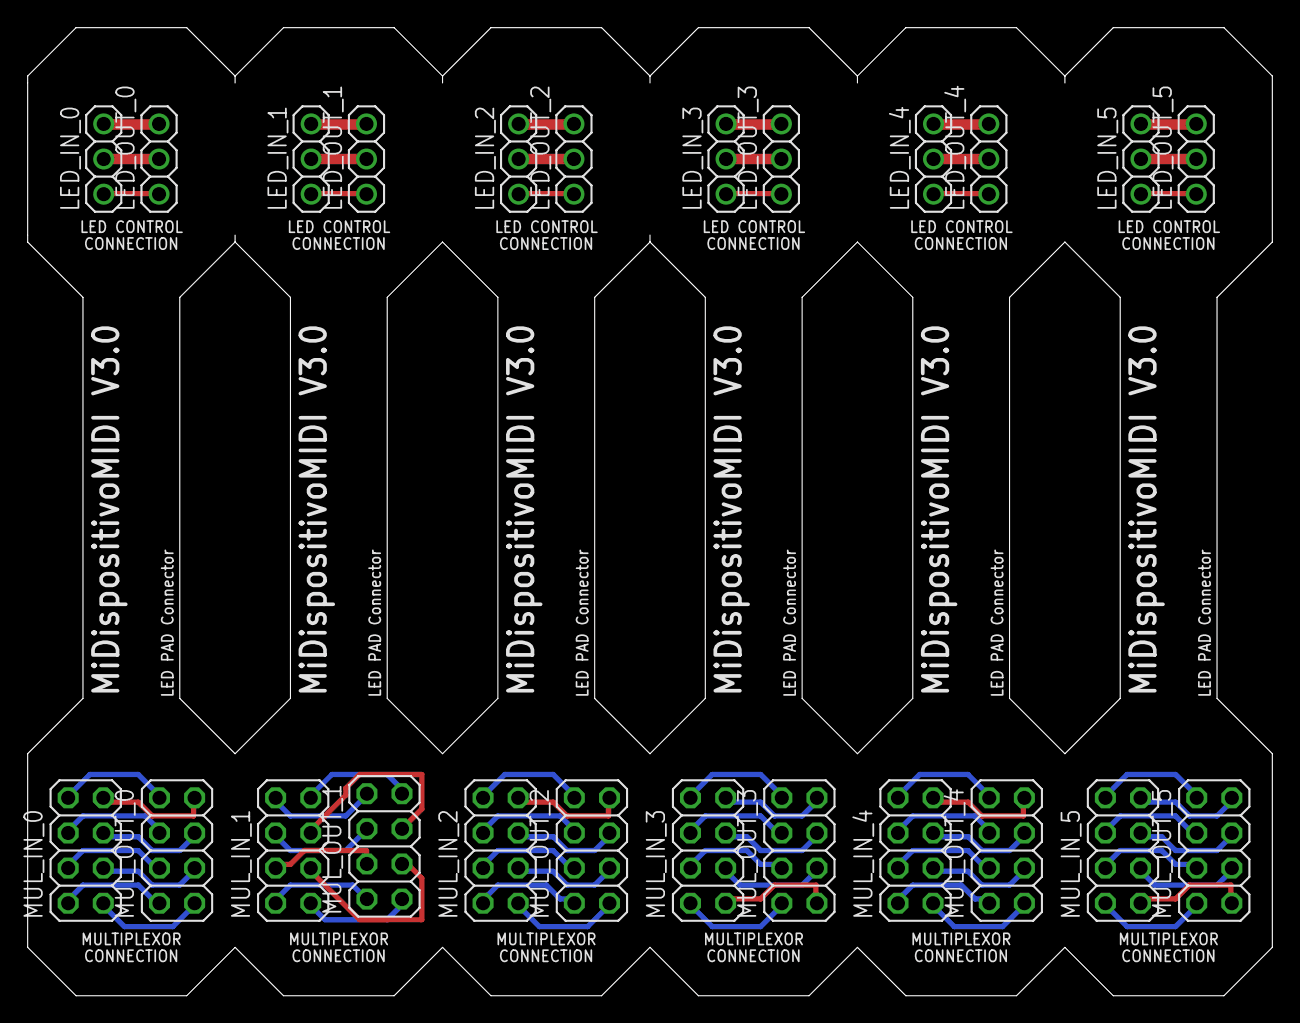
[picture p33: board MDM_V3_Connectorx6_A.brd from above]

Board: 2 copper layers, 90.0 x 70.0 mm, 24 parts (0 on the bottom side), 66 nets.

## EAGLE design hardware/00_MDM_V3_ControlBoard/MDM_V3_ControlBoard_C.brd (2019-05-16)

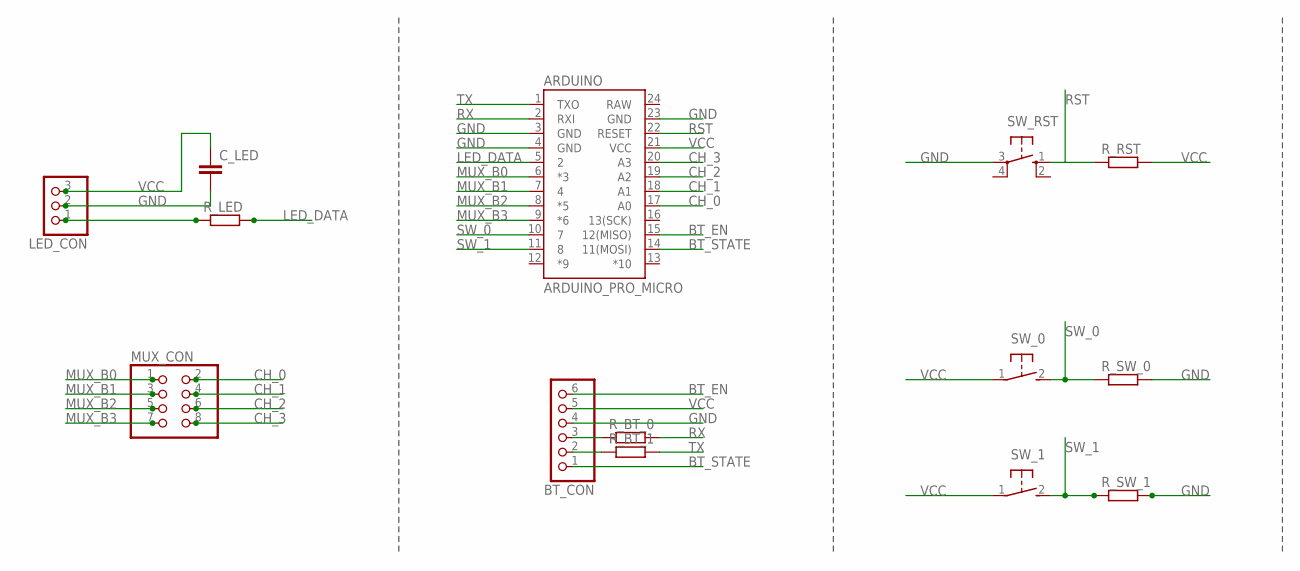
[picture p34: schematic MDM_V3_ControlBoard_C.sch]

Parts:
ARDUINO: ARDUINO_PRO_MICRO
BT_CON: PINHD-1X6; 1X06
C_LED: C-EUC1206K; C1206K
LED_CON: PINHD-1X3; 1X03
MUX_CON: PINHD-2X4; 2X04
R_BT_0, R_BT_1: R-EU_M1206; M1206
R_LED: R-EU_M1206; M1206
R_RST: R-EU_M1206; M1206
R_SW_0, R_SW_1: R-EU_M1206; M1206
SW_0, SW_1: 31-XX; B3F-31XX
SW_RST: 10-XX; B3F-10XX

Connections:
BT_EN: ARDUINO.15 (12(MISO)), BT_CON.6
BT_STATE: ARDUINO.14 (11(MOSI)), BT_CON.1
CH_0: ARDUINO.17 (A0), MUX_CON.2
CH_1: ARDUINO.18 (A1), MUX_CON.4
CH_2: ARDUINO.19 (A2), MUX_CON.6
CH_3: ARDUINO.20 (A3), MUX_CON.8
GND: ARDUINO.3 (GND), ARDUINO.4 (GND), ARDUINO.23 (GND), BT_CON.4, C_LED.2, LED_CON.2, R_SW_0.2, R_SW_1.2, SW_RST.3
LED_DATA: ARDUINO.5 (2), R_LED.2
MUX_B0: ARDUINO.6 (*3), MUX_CON.1
MUX_B1: ARDUINO.7 (4), MUX_CON.3
MUX_B2: ARDUINO.8 (*5), MUX_CON.5
MUX_B3: ARDUINO.9 (*6), MUX_CON.7
unnamed: BT_CON.2, R_BT_1.1
unnamed: BT_CON.3, R_BT_0.1
unnamed: LED_CON.1, R_LED.1
RST: ARDUINO.22 (RESET), R_RST.1, SW_RST.1 (S)
RX: ARDUINO.2 (RXI), R_BT_0.2
SW_0: ARDUINO.10 (7), R_SW_0.1, SW_0.2 (S)
SW_1: ARDUINO.11 (8), R_SW_1.1, SW_1.2 (S)
TX: ARDUINO.1 (TXO), R_BT_1.2
VCC: ARDUINO.21 (VCC), BT_CON.5, C_LED.1, LED_CON.3, R_RST.2, SW_0.1, SW_1.1

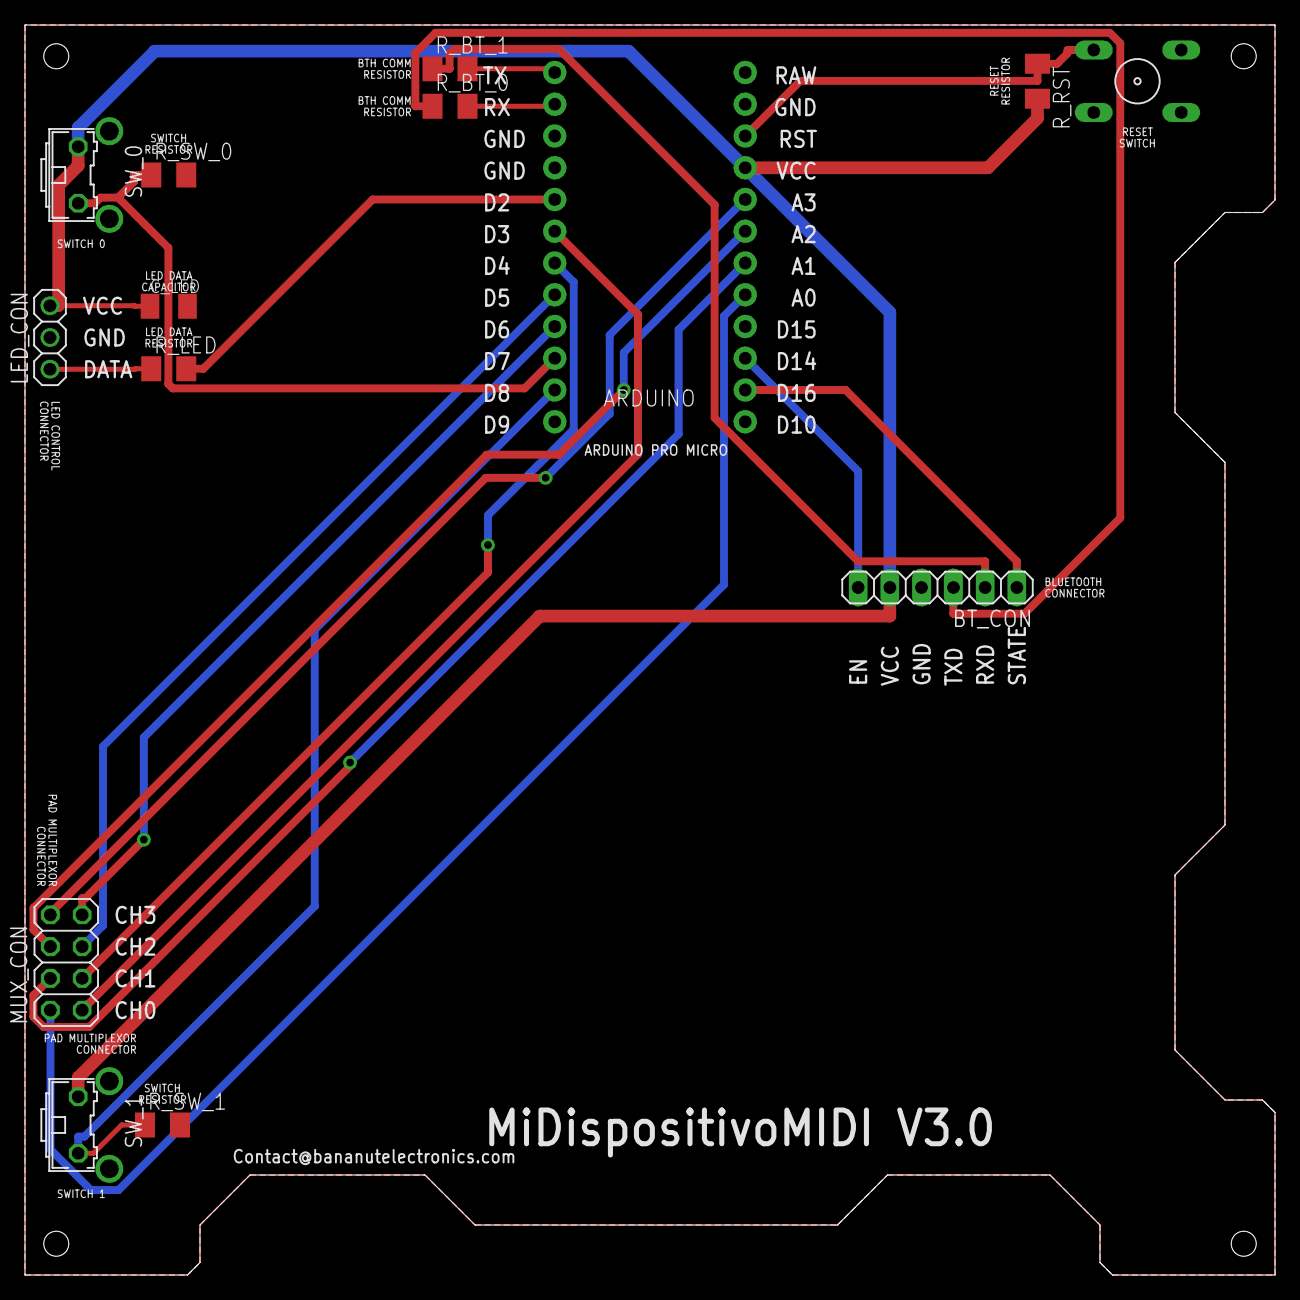
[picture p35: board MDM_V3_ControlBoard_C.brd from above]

Board: 2 copper layers, 100.0 x 100.0 mm, 14 parts (0 on the bottom side), 21 nets.

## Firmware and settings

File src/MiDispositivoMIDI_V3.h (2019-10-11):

/*
  2018 BanaNut Electronics (bananutelectronics@gmail.com)

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
  You are free to share, copy and redistribute the material in any medium
  or format, and also to adapt, remix, transform or build upon de provided
  material, always under the following terms:
    * Attribution                — You must give appropriate credit, provide a link
                                   to the license, and indicate if changes were made.
                                   You may do so in any reasonable manner, but not in any way
                                   that suggests the licensor endorses you or your use.
    * NonCommercial              — You may not use the material for commercial purposes.
    * ShareAlike                 — If you remix, transform, or build upon the material, you must
                                   distribute your contributions under the same license as the original.
    * No additional restrictions — You may not apply legal terms or technological measures that
                                   legally restrict others from doing anything the license permits.

  More informatio can be found in https://creativecommons.org/licenses/by-nc-sa/4.0/
*/

#ifndef MiDispositivoMIDI_V3_h
#define MiDispositivoMIDI_V3_h

// digital pin definition
#define LEDPAD_PIN  2
#define SW_0_PIN    7
#define SW_1_PIN    8

// analog pin definition
#define PADCH_0_PIN 0
#define PADCH_1_PIN 1
#define PADCH_2_PIN 2
#define PADCH_3_PIN 3

// mux pin definition 
#define MUX_B0_PIN 6
#define MUX_B1_PIN 5
#define MUX_B2_PIN 4
#define MUX_B3_PIN 3

// some definitions
#define N_ROWS         4
#define N_COLS         4
#define RGB_COLORS     3
#define LEDPAD_NUM     16
#define PAD_THR        500
#define MAX_EXTENSIONS 4
#define MUX_DELAY      50
#define USEC_IN_SEC    1000000
#define NUM_LATERAL_SWITCH 2

// some default values
#define DEFAULT_MIDI_CHANNEL 0
#define DEFAULT_ON_RED       0
#define DEFAULT_ON_GREEN     255
#define DEFAULT_ON_BLUE      0
#define DEFAULT_OFF_RED      255
#define DEFAULT_OFF_GREEN    255
#define DEFAULT_OFF_BLUE     255
#define DEFAULT_PAGE_NUM     0
#define DEFAULT_VELOCITY     127
#define MAX_NUMBER_OF_PAGES  4

enum HardwareConfigurations
{
  SINGLE_DEVICE_4X4,
  TWO_DEVICES_4X8,
  THREE_DEVICES_4X12,
  FOUR_DEVICES_4X16,
  FOUR_DEVICES_8X8
};

enum BoardRoles
{
  TOUCHPAD,
  POTENTIOMETER
};

class MiDispositivoMIDI_V3
{
public: 
    
    MiDispositivoMIDI_V3(HardwareConfigurations hwConfig, BoardRoles bRoles[MAX_EXTENSIONS]);
    ~MiDispositivoMIDI_V3();
    
    void loop();
    void initializeLEDs();
    void setMidiNotes(uint8_t notes[MAX_EXTENSIONS][LEDPAD_NUM]);
    void setMidiVeloc(uint8_t veloc[MAX_EXTENSIONS][LEDPAD_NUM]);
    void setOnColors(uint8_t rgbColors[RGB_COLORS]);
    void setOffColors(uint8_t rgbColors[RGB_COLORS]);
    void setPixelColor(uint8_t expansion,
                       uint8_t led,
                       uint8_t rgbColors[RGB_COLORS]);
    void setInterrupt(void (* functionPointer)(), double seconds);
    
protected:

    // when using more than one device, different configurations are possible
    HardwareConfigurations _hwConfig;

    // every 4x4 device can have buttons (PADs) or potentiometers
    BoardRoles _bRoles[MAX_EXTENSIONS];

    // number of hardware extensions [0:MAX_EXTENSIONS]
    uint8_t _numberExtensions;

    // n of rows of the hw setup, 4 for one device
    uint8_t _numOfRows;

    // n of cols of the hw setup, 4 for one device
    uint8_t _numOfCols;

    // color per led for all the device
    uint8_t _ledColors[MAX_EXTENSIONS][LEDPAD_NUM][RGB_COLORS] = {{{0}}};

    // last value read by each button
    uint8_t _lastRead[MAX_EXTENSIONS][LEDPAD_NUM]  = {{0}};

    // midi note sent by each button
    uint8_t _midiNotes[MAX_EXTENSIONS][LEDPAD_NUM] = {{0}};

    // midi velocity sent by each button
    uint8_t _midiVeloc[MAX_EXTENSIONS][LEDPAD_NUM] = {{0}};

    // default color for all leds when the button is on
    uint8_t _onColors[RGB_COLORS];

    // default color for all leds when the button is off
    uint8_t _offColors[RGB_COLORS];

    // each page sends different notes
    uint8_t _currentPage;

    void readPADs();
    void readPage();
    void updateLEDs();
    void setRgbColors(uint8_t copyFrom[RGB_COLORS],
                      uint8_t copyTo[RGB_COLORS]);

    void generateNotesVeloc(uint8_t numberOfExtensions);

    void noteOn(byte channel,
                byte pitch,
                byte velocity);

    void noteOff(byte channel,
                 byte pitch,
                 byte velocity);

    // Functions to be overrided by the user
    virtual void buttonPressed(uint8_t extension, uint8_t pad);
    virtual void buttonReleased(uint8_t extension, uint8_t pad);
    virtual void buttonHolded(uint8_t extension, uint8_t pad);
    virtual void potentiometerMoved(uint8_t extension, uint8_t pad, int value);
};

#endif

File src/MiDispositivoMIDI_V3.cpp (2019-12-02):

/*
  2018 BanaNut Electronics (bananutelectronics@gmail.com)

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
  You are free to share, copy and redistribute the material in any medium
  or format, and also to adapt, remix, transform or build upon de provided
  material, always under the following terms:
    * Attribution                — You must give appropriate credit, provide a link
                                   to the license, and indicate if changes were made.
                                   You may do so in any reasonable manner, but not in any way
                                   that suggests the licensor endorses you or your use.
    * NonCommercial              — You may not use the material for commercial purposes.
    * ShareAlike                 — If you remix, transform, or build upon the material, you must
                                   distribute your contributions under the same license as the original.
    * No additional restrictions — You may not apply legal terms or technological measures that
                                   legally restrict others from doing anything the license permits.

  More informatio can be found in https://creativecommons.org/licenses/by-nc-sa/4.0/
*/

#include "Arduino.h"
#include "MiDispositivoMIDI_V3.h"
#include <Adafruit_NeoPixel.h>
#include <MIDIUSB.h>
#include <TimerOne.h>

// neopixel library to handle all leds
Adafruit_NeoPixel ledPadStripe;

// last value read by the lateral switches
uint8_t lastSwitchRead[NUM_LATERAL_SWITCH] = {0, 0};

// pad channel pins
uint8_t padPin[4] = {PADCH_0_PIN,PADCH_1_PIN,PADCH_2_PIN,PADCH_3_PIN};

// mux selectior pins
uint8_t muxPin[4] = {MUX_B0_PIN,MUX_B1_PIN,MUX_B2_PIN,MUX_B3_PIN};

/*
* Function:    MiDispositivoMIDI_V3::MiDispositivoMIDI_V3
* Description: Constructor.

* Input:
*  -hwConfig  Hardware configuration. If only one board is used, use
              SINGLE_DEVICE_4X4. If you have more than one board connected,
              choose a configuration accordingly
*  -bRoles    Type of each board. Choose between POTENTIOMETER and TOUCHPAD.

* Output:
*  -void
*/
MiDispositivoMIDI_V3::MiDispositivoMIDI_V3(HardwareConfigurations hwConfig, BoardRoles bRoles[MAX_EXTENSIONS])
{
    _currentPage = DEFAULT_PAGE_NUM;
    _hwConfig    = hwConfig;

    switch (hwConfig)
    {
        case SINGLE_DEVICE_4X4:
            _numberExtensions = 1;
            _numOfRows = 4;
            _numOfCols = 4;
            break;
        case TWO_DEVICES_4X8:
            _numberExtensions = 2;
            _numOfRows = 4;
            _numOfCols = 8;
            break;
        case THREE_DEVICES_4X12:
            _numberExtensions = 3;
            _numOfRows = 4;
            _numOfCols = 12;
            break;
        case FOUR_DEVICES_4X16:
            _numberExtensions = 4;
            _numOfRows = 4;
            _numOfCols = 16;
            break;
        case FOUR_DEVICES_8X8:
            _numberExtensions = 4;
            _numOfRows = 8;
            _numOfCols = 8;
            break;
    }

    for (uint8_t i = 0; i < _numberExtensions; i++)
    {
      _bRoles[i] = bRoles[i];
    }

    // set some on/off colors by default
    uint8_t on[RGB_COLORS]  = {DEFAULT_ON_RED, DEFAULT_ON_GREEN, DEFAULT_ON_BLUE};
    uint8_t off[RGB_COLORS] = {DEFAULT_OFF_RED, DEFAULT_OFF_GREEN, DEFAULT_OFF_BLUE};
    setOnColors(on);
    setOffColors(off);

    // set pin modes
    pinMode(MUX_B0_PIN, OUTPUT);
    pinMode(MUX_B1_PIN, OUTPUT);
    pinMode(MUX_B2_PIN, OUTPUT);
    pinMode(MUX_B3_PIN, OUTPUT);
    pinMode(SW_0_PIN, INPUT);
    pinMode(SW_1_PIN, INPUT);

    // init led strip
    ledPadStripe = Adafruit_NeoPixel(LEDPAD_NUM * _numberExtensions, LEDPAD_PIN, NEO_RGB + NEO_KHZ800);
    ledPadStripe.begin();
    
    // set all leds to off color
    initializeLEDs();

    // generate which notes each button will send
    generateNotesVeloc(_numberExtensions);
}

/*
* Function:    MiDispositivoMIDI_V3::~MiDispositivoMIDI_V3
* Description: Destructor.

* Input:
*  -none

* Output:
*  -void
*/
MiDispositivoMIDI_V3::~MiDispositivoMIDI_V3()
{

}

/*
* Function:    MiDispositivoMIDI_V3::readPADs
* Description: Read all buttons and do some actions with them

* Input:
*  -none

* Output:
*  -void
*/
void MiDispositivoMIDI_V3::readPADs()
{
    // iterate all buttons in a pad
    for(int i = 0; i < LEDPAD_NUM; i++)
    {
        // configure the mux
        for(int h = 0; h < 4; h++)
        {
            digitalWrite(muxPin[h], ((i>>(3-h)) & 0x01));
        }
        delayMicroseconds(MUX_DELAY);

        // iterate all extensions
        for(int j = 0; j < _numberExtensions; j++)
        {
            // read the button
            int padRead = analogRead(padPin[j]);

            // If j extension is a TOUCHPAD matrix
            if (_bRoles[j] == TOUCHPAD)
            {
              // if lower than threshold, it has been pressed
              if (padRead < PAD_THR)
              { 
                  // only enter if it was not previously pressed
                  if (_lastRead[j][i] == 0)
                  {
                      _lastRead[j][i] = 1;
                      buttonPressed(j, i);
                  }
                  else
                  {
                      buttonHolded(j, i);
                  }
              }
              else
              {
                  // if it has been released
                  if (_lastRead[j][i] == 1)
                  {
                      _lastRead[j][i] = 0;
                      buttonReleased(j, i);
                  }
              }
              
            }
            // If j extension is a POTENTIOMETER matrix
            else if (_bRoles[j] == POTENTIOMETER)
            {
              potentiometerMoved(j, i, padRead);
            }
        }  
    }
}


/*
 * Function:    MiDispositivoMIDI_V3::buttonPressed
 * Description: Callback function when a button is pressed. It enters
 *              only once when the action happens. This function is
 *              only applicable when the extension is a pad one.

 * Input:
 *  -extension:  Extension that was pressed [0..3]
 *  -pad:        Pad that was pressed [0..15]

 * Output:
 *  -void
 */
void MiDispositivoMIDI_V3::buttonPressed(uint8_t extension, uint8_t pad)
{
    setRgbColors(_onColors, _ledColors[extension][pad]);
    noteOn(DEFAULT_MIDI_CHANNEL,
           _numberExtensions == 1 ? _midiNotes[extension][pad] + _currentPage * LEDPAD_NUM : _midiNotes[extension][pad],
           _midiVeloc[extension][pad]);

    MidiUSB.flush();
}
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

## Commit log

2019-02-23 Release Arduino library
    [MDM_V3_ControlBoard_C.brd, MDM_V3_ControlBoard_C.sch, MDM_V3_Cover.dxf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]
2019-05-09 Fix of misspellings/typos :+1:
    [MDM_V3_ControlBoard_C.brd]
2019-05-28 Use correct field separator in keywords.txt
    The Arduino IDE requires the use of a single true tab separator between the keyword name and identifier. When spaces are used rather than a true tab, the keyword is not highlighted.
    Reference:
    https://github.com/arduino/Arduino/wiki/Arduino-IDE-1.5:-Library-specification#keywords
2019-07-23 Add prototype of Automelody example (WIP)
    This example generates melodies following a probalistic model
    generated from MIDI files. Note probabilities and transition
    probabilities are considered in the decision of the next note.
    PADs 1 to 8 will control the note generation (things like going
    up or down in the scale)
    PADs 9 to 16 will reserved for controling which scale to use,
    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
2019-08-03 Modify library
    -Add new functions for button pressed/released/holded that can be overrided. This aims to make the device more flexible to new features.
    -Remove numPages variable from constructor, since its quite specific.
    TODO: This patch will break some examples. Fix this.
    [MiDispositivoMIDI_V3.cpp, MiDispositivoMIDI_V3.h]
2019-08-03 Automelody improvement
    This update add the following functionalities:
    - PADs 0 to 3 generates lower notes -(I, III, IV, V)
    - PADs 4 to 7 generates higher notes +(I, III, IV, V)
    - PADs 8 to 9 are octave up/down buttons
    - PADs 10 to 11 are semitone up/down buttons
    - PADs 12 to 15 are switches for the scale. You can choose among:
    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
2019-10-11 Add support for a 4x4 potentiometer extension
    Add support for a 4x4 potentiometers extension. With this new feature you can have your main 4x4 board with touch pads, and up to 3 potentiometers or touch pads extensions. All combinations are suppo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
2019-12-02 Comment buttonHolded handle
    Just comment out the buttonHolded handle.
2019-12-14 Merge master
    The API is updated to the current master version
    Next commits will update `Automelody` to comply with this version
    Main changes TODO:
    - Split PADaction() into individual actions
    - Remove note()
2019-12-19 Adapt to new API and improve behavior
    - buttons 0/7 control the range in which the new note can be selected
    - Note probs also depend on a Gaussian centered in the extreme of the
    range.
    The goal is to make the model more exprsesive by making it more likely
    to play notes that are further from the previous one
2019-12-19 Specify library dependencies in library.properties
    Specifying the library dependencies in the depends field of library.properties causes the Arduino Library Manager (Arduino IDE 1.8.10 and newer) to offer to install the dependencies during installati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
2020-01-26 Add pot pad expansion (NOT OFFICIALLY SUPPORTED)
    Add pot pad expansion (NOT OFFICIALLY SUPPORTED)
    [MDM_V3_Connectorx6_A.brd, MDM_V3_Connectorx6_A.sch, MDM_V3_PotPad_A.brd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]

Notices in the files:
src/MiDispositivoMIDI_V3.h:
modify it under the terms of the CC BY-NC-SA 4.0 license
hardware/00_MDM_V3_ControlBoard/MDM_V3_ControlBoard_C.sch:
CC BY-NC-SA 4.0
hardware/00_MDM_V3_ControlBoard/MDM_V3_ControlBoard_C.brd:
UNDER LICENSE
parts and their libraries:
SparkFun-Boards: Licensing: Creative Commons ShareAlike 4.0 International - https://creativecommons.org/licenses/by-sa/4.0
